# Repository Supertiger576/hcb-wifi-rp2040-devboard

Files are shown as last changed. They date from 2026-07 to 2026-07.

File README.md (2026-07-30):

# Wireless RP2040 Devboard

# About 
An RP2040 devboard created with a guide from Hack Club.  It contains a very similar pinout to the Raspberry Pi Pico.  I added the Raspberry Pi RM2 to allow wireless capabilities.

This project interested me as a lot of people have told me that devboards were useful.

# Schematic:



# PCB:



# 3D Model:



Fabrication files are in the devboard folder.  These same files are zipped for import in devboard.zip.

# Necessary Materials

| Id | Designator | Footprint | Quantity | Comment 
|----|---|---|---|---|
| 1  | C1,C10 | C_0402_1005Metric | 2 | 1uF | | |
| 2  | C2,C3,C4,C5,C6,C7,C8,C9,C11,C12,C17 | C_0402_1005Metric | 11 | 0.1uF | | |
| 3  | C13,C14,C18,C19 | C_0603_1608Metric | 4 | 10uF | | |
| 4  | C15,C16 | C_0402_1005Metric | 2 | 33pF | | |
| 5  | J2, J3 | PinHeader_1x20_P2.54mm_Vertical | 2 | Conn_01x20 | | |
| 6  | J4 | PinHeader_1x03_P2.54mm_Vertical | 1 | Conn_01x03 | | |
| 7  | R1,R2,R3,R9 | R_0402_1005Metric | 4 | 5.1k | | |
| 8  | R4,R5 | R_0402_1005Metric | 2 | 27 | | |
| 9  | R6,R7 | R_0402_1005Metric | 2 | 1k | | |
| 10 | R8,R12 | R_0402_1005Metric | 2 | 10k | | |
| 11 | R11 | R_0402_1005Metric | 1 | 470 | | |
| 12 | RM2 | RMC20452T | 1 | RM2 | | |
| 13 | SW1 | SW_Push_SPST_NO_Alps_SKRK | 1 | Button | | |
| 14 | U1 | QFN-56-1EP_7x7mm_P0.4mm_EP3.2x3.2mm | 1 | RP2040 | | |
| 15 | U2 | Winbond_USON-8-1EP_3x2mm_P0.5mm_EP0.2x1.6mm | 1 | Flash Memory | | |
| 16 | U3,U4 | SOT-23 | 2 | Voltage Regulator | | |
| 17 | USB-C Plug | USB_C_Plug_JAE_DX07P024AJ1 | 1 | USB_C_Plug_USB2.0 | | |
| 18 | USB-C Receptacle | USB_C_Receptacle_HRO_TYPE-C-31-M-12 | 1 | USB_C_Receptacle_USB2.0_14P | | |
| 19 | Y1 | Crystal_SMD_3225-4Pin_3.2x2.5mm | 1 | Crystal | | |

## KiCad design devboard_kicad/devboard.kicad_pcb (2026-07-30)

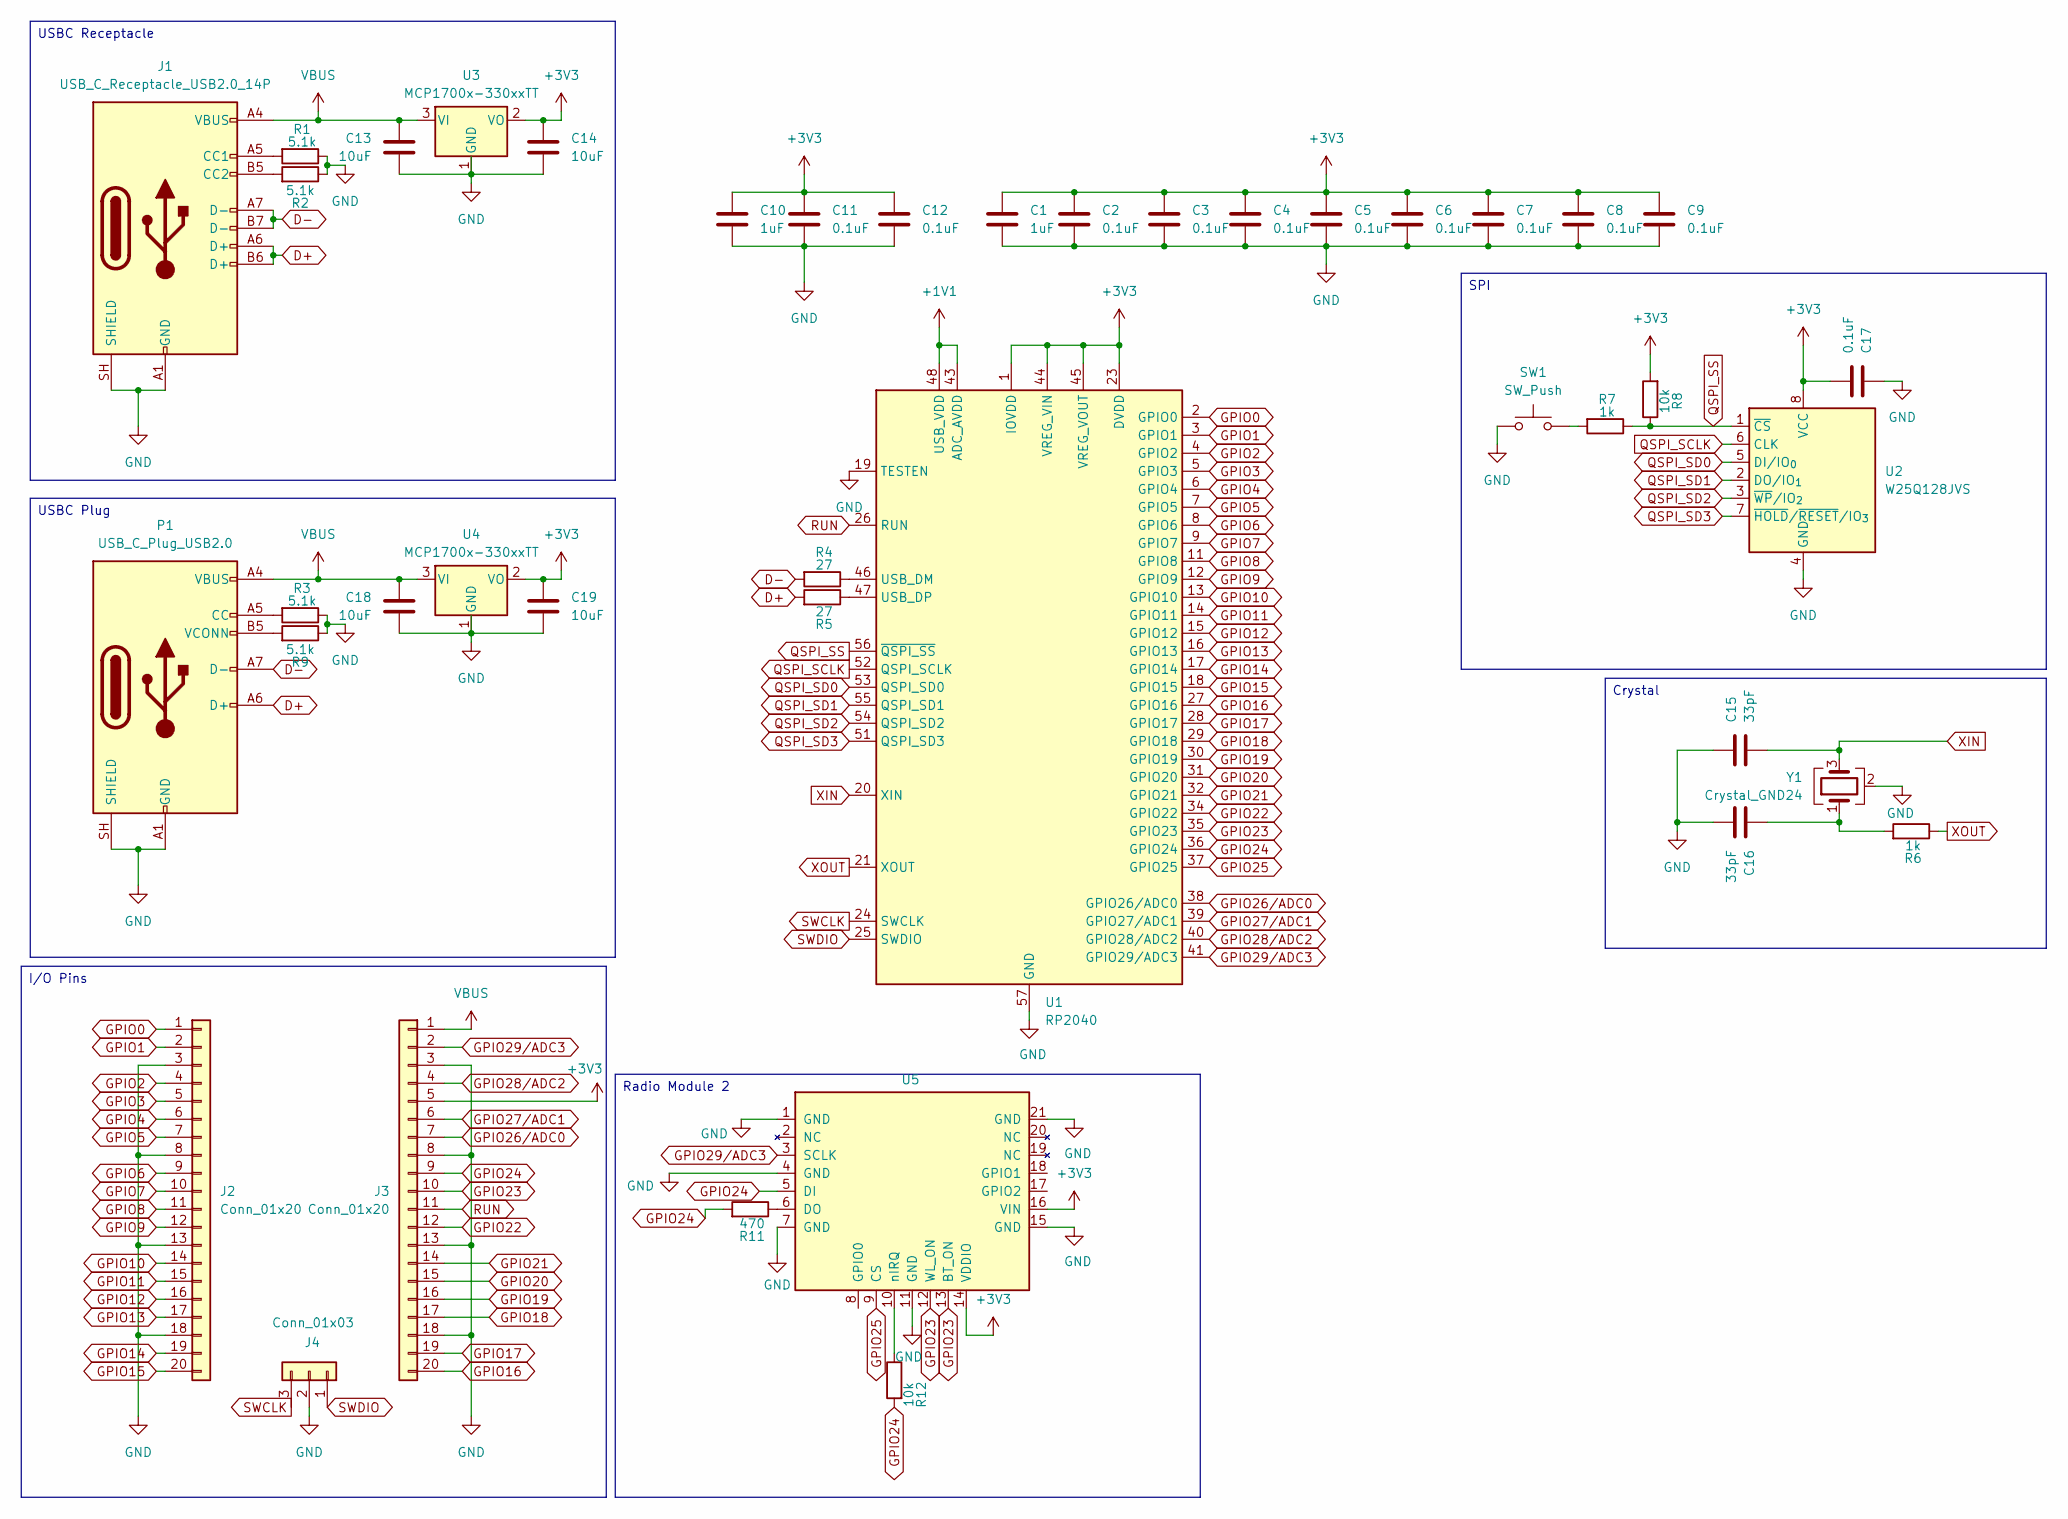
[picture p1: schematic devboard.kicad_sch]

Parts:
C1, C10: 1uF; C_0402_1005Metric
C2, C3, C4, C5, C6, C7, C8, C9, C11, C12, C17: 0.1uF; C_0402_1005Metric
C13, C14, C18, C19: 10uF; C_0603_1608Metric
C15, C16: 33pF; C_0402_1005Metric
J1: USB_C_Receptacle_USB2.0_14P; USB_C_Receptacle_HRO_TYPE-C-31-M-12
J2, J3: Conn_01x20; PinHeader_1x20_P2.54mm_Vertical
J4: Conn_01x03; PinHeader_1x03_P2.54mm_Vertical
P1: USB_C_Plug_USB2.0; USB_C_Plug_JAE_DX07P024AJ1
R1, R2, R3, R9: 5.1k; R_0402_1005Metric
R4, R5: 27; R_0402_1005Metric
R6, R7: 1k; R_0402_1005Metric
R8, R12: 10k; R_0402_1005Metric
R11: 470; R_0402_1005Metric
SW1: SW_Push; SW_Push_SPST_NO_Alps_SKRK
U1: RP2040; QFN-56-1EP_7x7mm_P0.4mm_EP3.2x3.2mm
U2: W25Q128JVS; SOIC-8_5.3x5.3mm_P1.27mm
U3, U4: MCP1700x-330xxTT; SOT-23
U5: RM2; RMC20452T
Y1: Crystal_GND24; Crystal_SMD_3225-4Pin_3.2x2.5mm

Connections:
+1V1: U1.43 (ADC_AVDD), U1.48 (USB_VDD)
+3V3: C1.1, C2.1, C3.1, C4.1, C5.1, C6.1, C7.1, C8.1, C9.1, C10.1, C11.1, C12.1, C14.1, C17.2, C19.1, J3.5, R8.2, U1.1 (IOVDD), U1.10 (IOVDD), U1.22 (IOVDD), U1.23 (DVDD), U1.33 (IOVDD), U1.42 (IOVDD), U1.44 (VREG_VIN), U1.45 (VREG_VOUT), U1.49 (IOVDD), U1.50 (DVDD), U2.8 (VCC), U3.2 (VO), U4.2 (VO), U5.14 (VDDIO), U5.16 (VIN); also elsewhere on the board
D+: J1.A6 (D+), J1.B6 (D+), P1.A6 (D+), R5.2; also elsewhere on the board
D-: J1.A7 (D-), J1.B7 (D-), P1.A7 (D-), R4.2; also elsewhere on the board
GND: C1.2, C2.2, C3.2, C4.2, C5.2, C6.2, C7.2, C8.2, C9.2, C10.2, C11.2, C12.2, C13.2, C14.2, C15.1, C16.2, C17.1, C18.2, C19.2, J1.A1 (GND), J1.A12 (GND), J1.B1 (GND), J1.B12 (GND), J1.SH (SHIELD), J2.3, J2.8, J2.13, J2.18, J3.3, J3.8, J3.13, J3.18, J4.2, P1.A1 (GND), P1.A12 (GND), P1.B1 (GND), P1.B12 (GND), P1.SH (SHIELD), R1.1, R2.1, R3.1, R9.1, SW1.1, U1.19 (TESTEN), U1.57 (GND), U2.4 (GND), U3.1 (GND), U4.1 (GND), U5.1 (GND), U5.4 (GND), U5.7 (GND), U5.11 (GND), U5.15 (GND), U5.21 (GND), Y1.2 (G), Y1.4 (G); also elsewhere on the board
GPIO0: J2.1, U1.2 (GPIO0)
GPIO1: J2.2, U1.3 (GPIO1)
GPIO2: J2.4, U1.4 (GPIO2)
GPIO3: J2.5, U1.5 (GPIO3)
GPIO4: J2.6, U1.6 (GPIO4)
GPIO5: J2.7, U1.7 (GPIO5)
GPIO6: J2.9, U1.8 (GPIO6)
GPIO7: J2.10, U1.9 (GPIO7)
GPIO8: J2.11, U1.11 (GPIO8)
GPIO9: J2.12, U1.12 (GPIO9)
GPIO10: J2.14, U1.13 (GPIO10)
GPIO11: J2.15, U1.14 (GPIO11)
GPIO12: J2.16, U1.15 (GPIO12)
GPIO13: J2.17, U1.16 (GPIO13)
GPIO14: J2.19, U1.17 (GPIO14)
GPIO15: J2.20, U1.18 (GPIO15)
GPIO16: J3.20, U1.27 (GPIO16)
GPIO17: J3.19, U1.28 (GPIO17)
GPIO18: J3.17, U1.29 (GPIO18)
GPIO19: J3.16, U1.30 (GPIO19)
GPIO20: J3.15, U1.31 (GPIO20)
GPIO21: J3.14, U1.32 (GPIO21)
GPIO22: J3.12, U1.34 (GPIO22)
GPIO23: J3.10, U1.35 (GPIO23), U5.12 (WL_ON), U5.13 (BT_ON); also elsewhere on the board
GPIO24: J3.9, R11.2, R12.2, U1.36 (GPIO24), U5.5 (DI); also elsewhere on the board
GPIO25: U1.37 (GPIO25), U5.9 (CS); also elsewhere on the board
GPIO26/ADC0: J3.7, U1.38 (GPIO26/ADC0)
GPIO27/ADC1: J3.6, U1.39 (GPIO27/ADC1)
GPIO28/ADC2: J3.4, U1.40 (GPIO28/ADC2)
GPIO29/ADC3: J3.2, U1.41 (GPIO29/ADC3), U5.3 (SCLK); also elsewhere on the board
unnamed: C16.1, R6.2, Y1.1
unnamed 36: J1.A5 (CC1), R1.2; also elsewhere on the board
unnamed 37: J1.B5 (CC2), R2.2; also elsewhere on the board
unnamed 38: P1.A5 (CC), R3.2; also elsewhere on the board
unnamed 39: P1.B5 (VCONN), R9.2; also elsewhere on the board
unnamed: R7.2, SW1.2
unnamed: R4.1, U1.46 (USB_DM)
unnamed: R5.1, U1.47 (USB_DP)
unnamed 43: R11.1, U5.6 (DO); also elsewhere on the board
unnamed 44: R12.1, U5.10 (nIRQ); also elsewhere on the board
QSPI_SCLK: U1.52 (QSPI_SCLK), U2.6 (CLK)
QSPI_SD0: U1.53 (QSPI_SD0), U2.5 (DI/IO_{0})
QSPI_SD1: U1.55 (QSPI_SD1), U2.2 (DO/IO_{1})
QSPI_SD2: U1.54 (QSPI_SD2), U2.3 (~WP/IO_{2})
QSPI_SD3: U1.51 (QSPI_SD3), U2.7 (~HOLD/~RESET/IO_{3})
QSPI_SS: R7.1, R8.1, U1.56 (~QSPI_SS), U2.1 (~CS)
RUN: J3.11, U1.26 (RUN)
SWCLK: J4.3, U1.24 (SWCLK)
SWDIO: J4.1, U1.25 (SWDIO)
VBUS: C13.1, C18.1, J1.A4 (VBUS), J1.A9 (VBUS), J1.B4 (VBUS), J1.B9 (VBUS), J3.1, P1.A4 (VBUS), P1.A9 (VBUS), P1.B4 (VBUS), P1.B9 (VBUS), U3.3 (VI), U4.3 (VI); also elsewhere on the board
XIN: C15.2, U1.20 (XIN), Y1.3
XOUT: R6.1, U1.21 (XOUT)

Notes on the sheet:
Crystal
USBC Receptacle
Radio Module 2
SPI
USBC Plug
I/O Pins

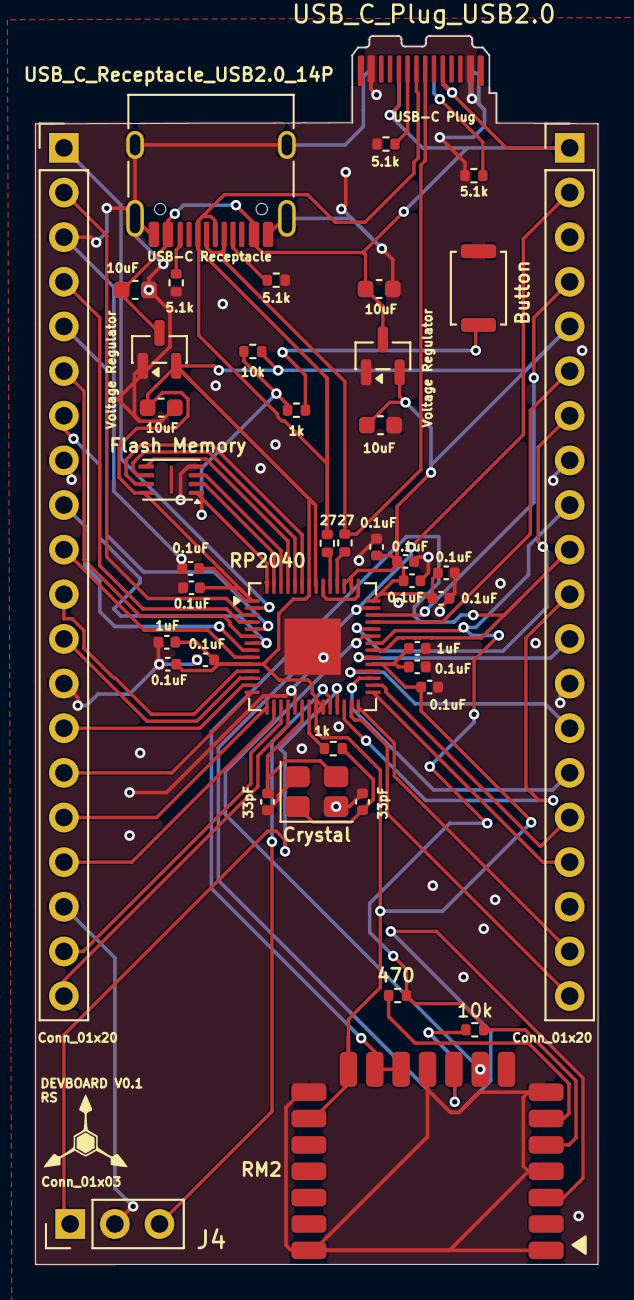
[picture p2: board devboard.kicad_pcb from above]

Board: 2 copper layers, 32.0 x 69.9 mm, 42 parts (0 on the bottom side), 57 nets.

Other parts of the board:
RM2: RM2; RMC20452T
USB-C Plug: USB_C_Plug_USB2.0; USB_C_Plug_JAE_DX07P024AJ1
USB-C Receptacle: USB_C_Receptacle_USB2.0_14P; USB_C_Receptacle_HRO_TYPE-C-31-M-12

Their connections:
+3V3: RM2.14 (VDDIO), RM2.16 (VIN); also elsewhere on the board
D+: USB-C Plug.A6 (D+), USB-C Receptacle.A6 (D+), USB-C Receptacle.B6 (D+); also elsewhere on the board
D-: USB-C Plug.A7 (D-), USB-C Receptacle.A7 (D-), USB-C Receptacle.B7 (D-); also elsewhere on the board
GND: RM2.1 (GND), RM2.4 (GND), RM2.7 (GND), RM2.11 (GND), RM2.15 (GND), RM2.21 (GND), USB-C Plug.A1 (GND), USB-C Plug.A12 (GND), USB-C Plug.B1 (GND), USB-C Plug.B12 (GND), USB-C Plug.SH (SHIELD), USB-C Receptacle.A1 (GND), USB-C Receptacle.A12 (GND), USB-C Receptacle.B1 (GND), USB-C Receptacle.B12 (GND), USB-C Receptacle.SH (SHIELD); also elsewhere on the board
GPIO23: RM2.12 (WL_ON), RM2.13 (BT_ON); also elsewhere on the board
GPIO24: RM2.5 (DI); also elsewhere on the board
GPIO25: RM2.9 (CS); also elsewhere on the board
GPIO29/ADC3: RM2.3 (SCLK); also elsewhere on the board
unnamed 36: USB-C Receptacle.A5 (CC1); also elsewhere on the board
unnamed 37: USB-C Receptacle.B5 (CC2); also elsewhere on the board
unnamed 38: USB-C Plug.A5 (CC); also elsewhere on the board
unnamed 39: USB-C Plug.B5 (VCONN); also elsewhere on the board
unnamed 43: RM2.6 (DO); also elsewhere on the board
unnamed 44: RM2.10 (nIRQ); also elsewhere on the board
VBUS: USB-C Plug.A4 (VBUS), USB-C Plug.A9 (VBUS), USB-C Plug.B4 (VBUS), USB-C Plug.B9 (VBUS), USB-C Receptacle.A4 (VBUS), USB-C Receptacle.A9 (VBUS), USB-C Receptacle.B4 (VBUS), USB-C Receptacle.B9 (VBUS); also elsewhere on the board
